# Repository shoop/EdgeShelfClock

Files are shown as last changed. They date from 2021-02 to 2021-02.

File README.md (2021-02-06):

# Edge Shelf Clock
This is my version of [the Edge Shelf Clock](https://www.diymachines.co.uk/how-to-build-a-giant-hidden-shelf-edge-clock). Notably it uses 4 full digits to accomodate 24 hour clock.

Documentation in the `docs` folder:
- construction.drawio - drawing of the parameters when constructing
- schematic.fzz - Fritzing file for the breadboard setup

Also some datasheets for the used components.

BOM:
- 1 x ESP8266
- 1 x DS3231 RTC module
- 1 x PhotoResistor module for Arduino
- 1 x barrel jack connector
- 2 x 470 ohm resistor
- 1 x 1000uF capacitor
- 1 x 5V 10A power supply with barrel jack
- 1 x AdaFruit perma proto board
- red/green/black wire
- printed components (see `3dprinter` folder and [thingiverse](https://www.thingiverse.com/thing:4207524))
- wooden backboard
- screws

Tools in the `tools/` subfolder are not very configurable but work on my Linux machine. Adjust to taste.

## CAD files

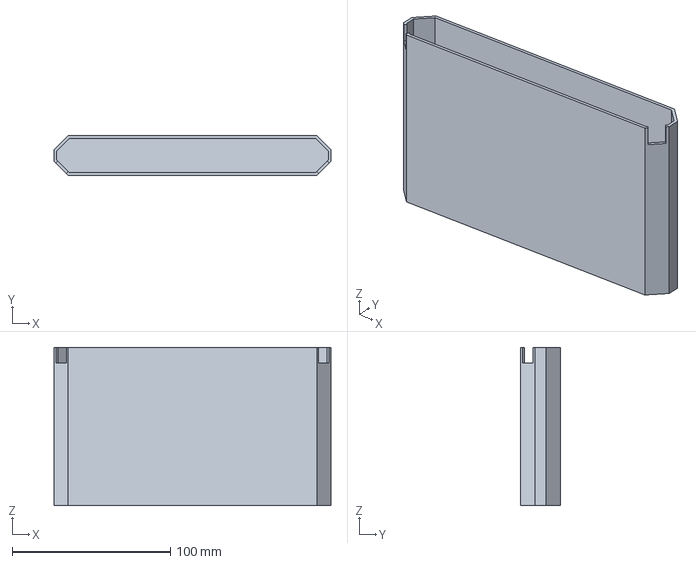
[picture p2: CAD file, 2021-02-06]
3dprinter/DualColored - Sleeve 1.3mf
175.0 x 25.0 x 100.0 mm

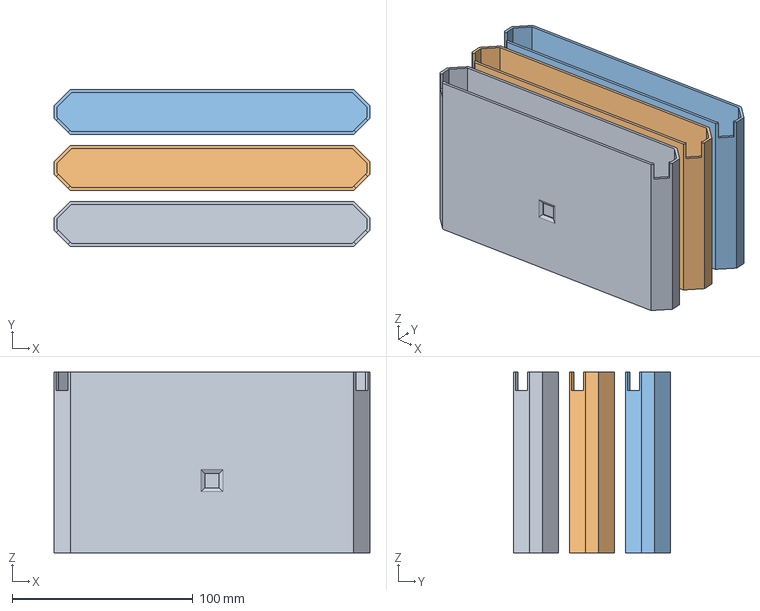
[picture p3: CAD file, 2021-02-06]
3dprinter/DualColored - Sleeve 2.3mf
175.0 x 87.0 x 100.0 mm
Sleeve2.STL x 3

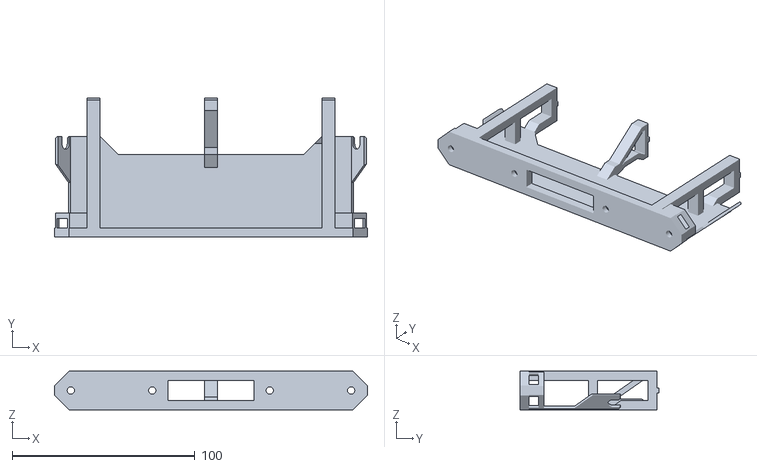
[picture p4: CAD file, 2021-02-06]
3dprinter/STL/Core4-Arduino.STL
171.1 x 76.0 x 21.1

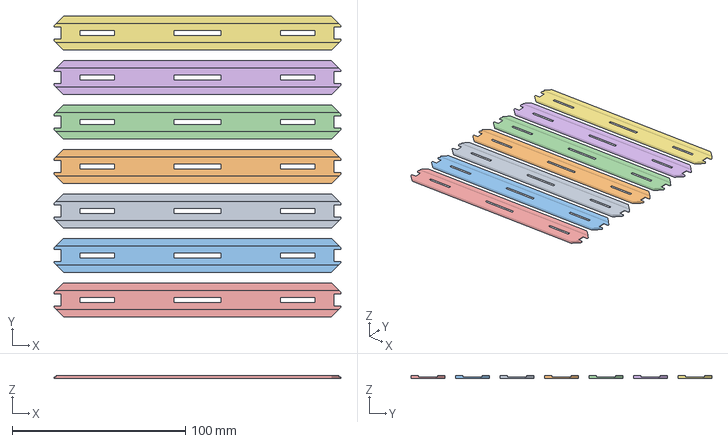
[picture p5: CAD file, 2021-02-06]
3dprinter/LEDMounts.3mf
165.7 x 173.9 x 2.00 mm
LEDMount.STL x 7

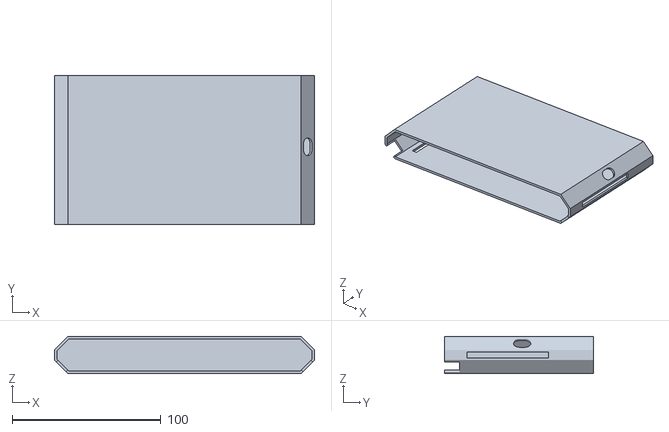
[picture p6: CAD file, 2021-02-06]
3dprinter/STL/Sleeve5.STL
175.0 x 100.0 x 25.0

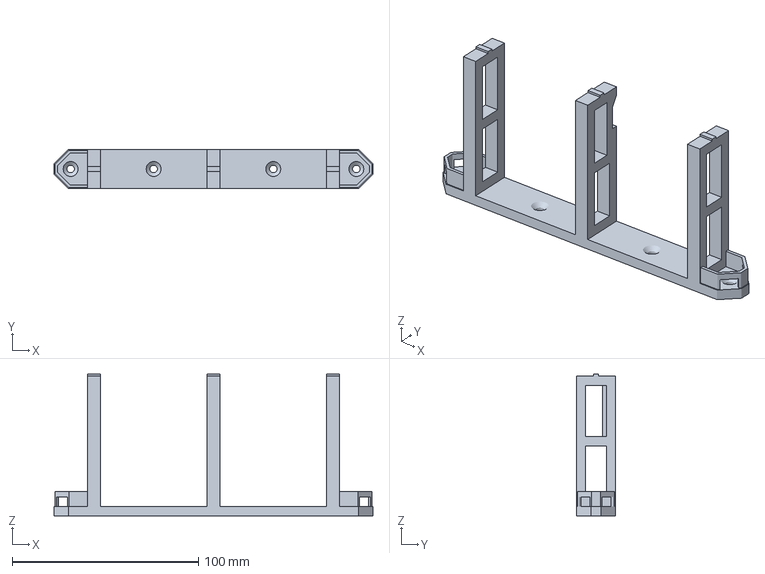
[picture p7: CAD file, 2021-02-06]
3dprinter/Core 2.3mf
171.1 x 21.1 x 76.0 mm

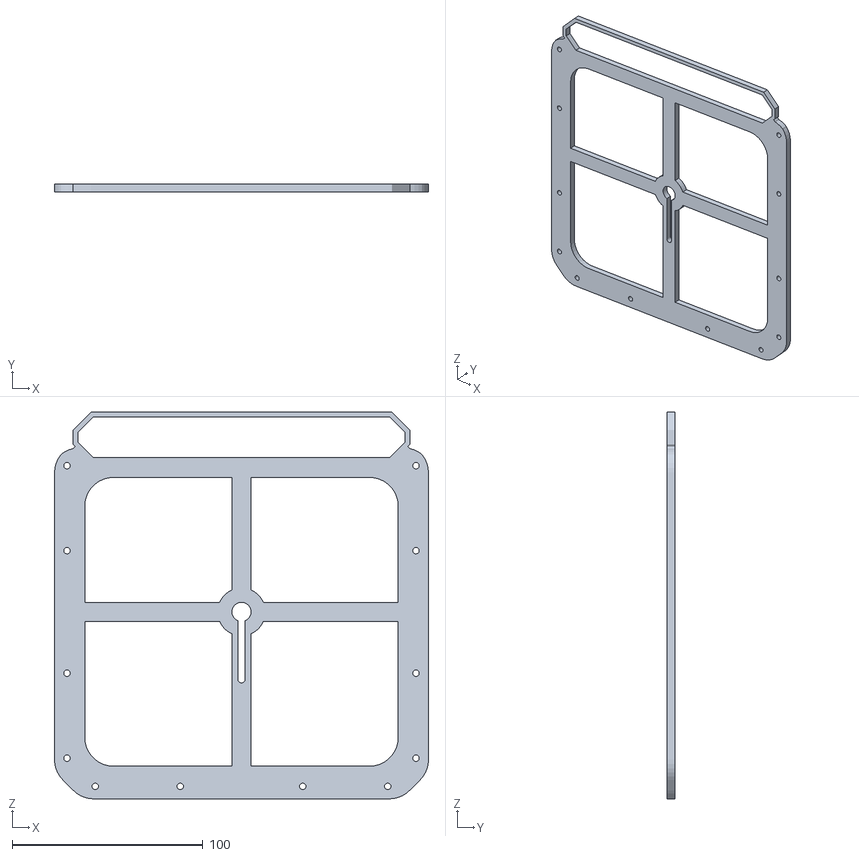
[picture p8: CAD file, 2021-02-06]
3dprinter/STL/Template2.STL
195.9 x 4.00 x 202.6

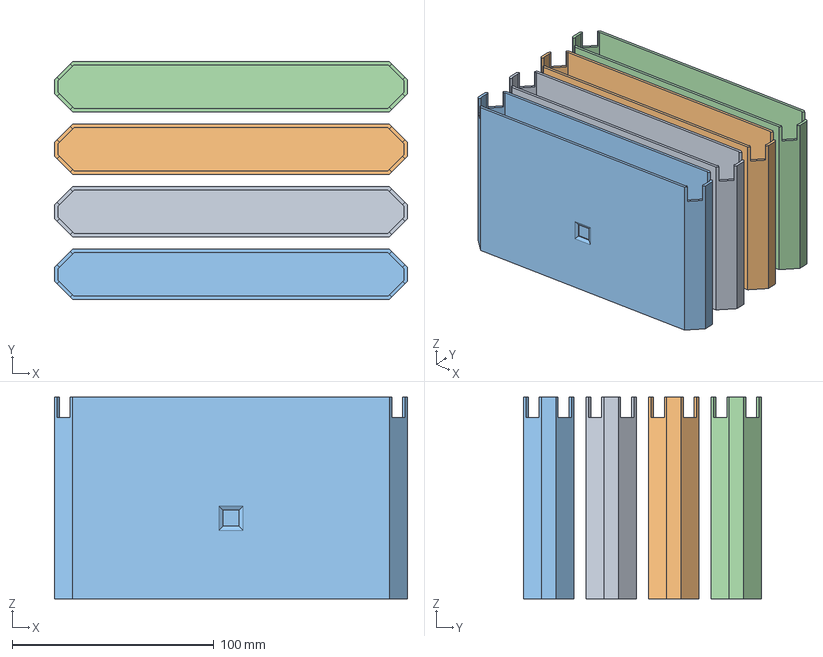
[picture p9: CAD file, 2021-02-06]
3dprinter/DualColored - Sleeve 4.3mf
175.0 x 118.0 x 100.0 mm
Sleeve4.STL x 4

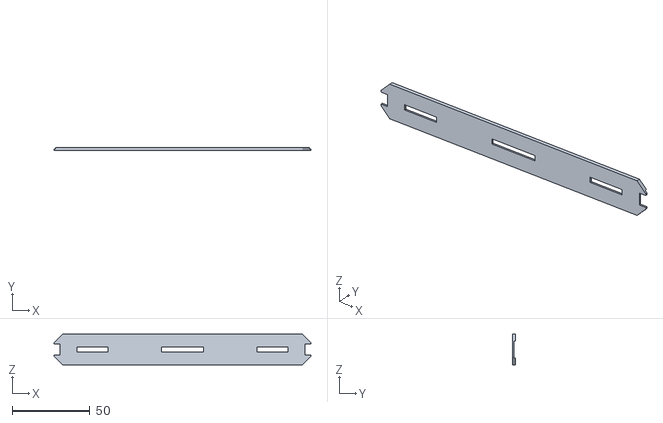
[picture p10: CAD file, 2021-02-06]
3dprinter/STL/LEDMount.STL
165.7 x 2.00 x 19.7

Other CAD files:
3dprinter/STL/Sleeve1.STL
3dprinter/DualColored - Sleeve 3.3mf
3dprinter/STL/Sleeve4.STL
3dprinter/STL/Sleeve3.STL
3dprinter/DualColored - Sleeve 5.3mf
3dprinter/STL/Sleeve2.STL
3dprinter/STL/Core2.STL

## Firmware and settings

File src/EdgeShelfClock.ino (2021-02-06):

#define OTA_VERSION 1

// WiFi connection
#include <ESP8266WiFi.h>
#include <ESP8266WebServer.h>

/*
 * Enter your SSID & Password here to connect for the first time.
 * Once the sketch has been run at least once, the values will be stored
 * on the ESP8266 by the WiFi system. You can then safely remove them
 * from here again and leave the empty string -- this will reconnect
 * to your previous AP.
 */
const char *ssid = "";
const char *password = "";

// Filesystem
#include <LittleFS.h>

// LED configuration
#define FASTLED_ESP8266_RAW_PIN_ORDER
#include <FastLED.h>
#define CLOCK_PIN 14 // GPIO14 aka D5
#define SHELF_PIN 12 // GPIO12 aka D6

#define NR_LINE_LEDS 9
#define NR_DIGIT_LEDS (NR_LINE_LEDS * 7)
#define NR_DIGITS 4
#define NR_CLOCK_LEDS (NR_DIGITS * NR_DIGIT_LEDS)
#define NR_SHELF_LEDS 14

#define MAX_BRIGHTNESS 128

CRGB clockleds[NR_CLOCK_LEDS];
CRGB clockcolor = CRGB::White;
int clockBrightness = MAX_BRIGHTNESS / 2;
CRGB shelfleds[NR_SHELF_LEDS];
CRGB shelfcolor = CRGB::White;
int shelfBrightness = MAX_BRIGHTNESS / 2;

enum StripState {
  Off = 0,
  On = 1,
};

// Numbered backwards for easy offsets
enum ClockDigit {
  M2 = 0,
  M1 = 1,
  H2 = 2,
  H1 = 3,
};

enum StripState clockstatus = On;
enum StripState shelfstatus = Off;

#define FRAMES_PER_SECOND  60

// Uncomment for the real clock, otherwise 8 test leds are used
#define REAL_CLOCK_STRIP 1

// Webserver configuration
ESP8266WebServer server(80);
String prehtml;
String posthtml;

// Real time clock and NTP
#include <Wire.h>
#define I2S_SDA_PIN 4 // GPIO4 aka D2
#define I2S_SCL_PIN 5 // GPIO5 aka D1

#include <AceRoutine.h>
#include <AceTime.h>
using namespace ace_routine;
using namespace ace_time;
using namespace ace_time::clock;

DS3231Clock dsClock;
NtpClock ntpClock("europe.pool.ntp.org");
SystemClockCoroutine systemClock(&ntpClock, &dsClock);
static BasicZoneProcessor zoneProcessor;

#define VERBOSE 0

// Photoresistor
#define NUM_READINGS  12
int readings[NUM_READINGS];
int readIndex = 0;
long total = 0;
long average = 0;

// OTA
#include <ArduinoOTA.h>
#define OTA_HOSTNAME "edgeshelfclock"
// admin123
// Change to something for your environment
#define OTA_PASSWORD_HASH "0192023a7bbd73250516f069df18b500"

String otaVersion = String(OTA_VERSION);

void setup()
{
  Serial.begin(115200);
  delay(1000);
  Serial.println();

  // Set up leds
  Serial.printf("Setting up clock pixel strip on pin %d\n", CLOCK_PIN);
  FastLED.addLeds<NEOPIXEL, CLOCK_PIN>(clockleds, NR_CLOCK_LEDS);
  Serial.printf("Setting up shelf pixel strip on pin %d\n", SHELF_PIN);
  FastLED.addLeds<NEOPIXEL, SHELF_PIN>(shelfleds, NR_SHELF_LEDS);

  // Initialize brightness settings
  FastLED.setBrightness(MAX_BRIGHTNESS);
  for (int i = 0; i < NUM_READINGS; i++) {
    readings[i] = 0;
  }

  // Set up filesystem
  LittleFS.begin();

  // Set up WiFi
  if (ssid != "") {
    Serial.printf("Connecting to SSID \"%s\"", ssid);
  } else {
    Serial.print(F("Connecting to previously defined AP"));
  }
  WiFi.begin(ssid, password);
  while (WiFi.status() != WL_CONNECTED) {
    delay(1000);
    Serial.print(".");
  }
  Serial.println("");
  Serial.printf("Connected, IP %s\n", WiFi.localIP().toString().c_str());

  // Set up RTC and NTP
  Serial.printf("Setting up I2S bus SDA pin %d SCL pin %d\n", I2S_SDA_PIN, I2S_SCL_PIN);
  Wire.begin(I2S_SDA_PIN, I2S_SCL_PIN);
  Serial.println(F("Setting up DS3231 RTC"));
  dsClock.setup();
  Serial.println(F("Setting up NTP"));
  ntpClock.setup();
  Serial.println(F("Setting up SystemClock coroutine"));
  systemClock.setupCoroutine(F("systemClock"));
  CoroutineScheduler::setup();

  // Print current RTC time for debugging
  Serial.print(F("RTC current date/time at startup: "));
  auto tz = TimeZone::forZoneInfo(&zonedb::kZoneEurope_Amsterdam, &zoneProcessor);
  acetime_t rtcNow = dsClock.getNow();
  auto rtcDateTime = ZonedDateTime::forEpochSeconds(rtcNow, tz);
  rtcDateTime.printTo(Serial);
  Serial.println();

  // Set up webserver
  File templ = LittleFS.open("/template.html", "r");
  if (!templ) {
    Serial.println(F("ERROR: HTML template /template.html not found, looping!"));
    while (1) ;
  }
  prehtml = templ.readStringUntil('@');
  posthtml = templ.readString();
  templ.close();

  Serial.println(F("Starting webserver..."));
  server.on("/", handleConnect);
  server.on("/set", HTTP_POST, handleSet);
  server.onNotFound(handleNotFound);
  server.begin();

  // Set up OTA
  ArduinoOTA.setPort(8266); // Default
  ArduinoOTA.setHostname(OTA_HOSTNAME);
  ArduinoOTA.setPasswordHash(OTA_PASSWORD_HASH);

  ArduinoOTA.onStart([]() {
    String type;
    if (ArduinoOTA.getCommand() == U_FLASH) {
      type = "sketch";
    } else { // U_FS
      type = "filesystem";
    }

    // NOTE: if updating FS this would be the place to unmount FS using FS.end()
    LittleFS.end();
    Serial.println("Start updating " + type);
  });
  ArduinoOTA.onEnd([]() {
    Serial.println("\nEnd");
  });
  ArduinoOTA.onProgress([](unsigned int progress, unsigned int total) {
    Serial.printf("Progress: %u%%\r", (progress / (total / 100)));
  });
  ArduinoOTA.onError([](ota_error_t error) {
    Serial.printf("Error[%u]: ", error);
    if (error == OTA_AUTH_ERROR) {
      Serial.println("Auth Failed");
    } else if (error == OTA_BEGIN_ERROR) {
      Serial.println("Begin Failed");
    } else if (error == OTA_CONNECT_ERROR) {
      Serial.println("Connect Failed");
    } else if (error == OTA_RECEIVE_ERROR) {
      Serial.println("Receive Failed");
    } else if (error == OTA_END_ERROR) {
      Serial.println("End Failed");
    }
  });
  ArduinoOTA.begin();

  // Ready
  Serial.printf("Accepting connections at http://%s\n", WiFi.localIP().toString().c_str());
}

void clearClock()
{
  fill_solid(clockleds, NR_CLOCK_LEDS, CRGB::Black);
}

void setClockDigitTest(int value, ClockDigit digit, CRGB color)
{
  // Use the first 8 leds I have on the test strip to "display the time"
  int offset = digit * 2;
  CRGB mapping[5] = { CRGB::Red, CRGB::Blue, CRGB::Yellow, CRGB::Green, CRGB::White };

  switch (value % 10) {
    case 0:
    case 1:
    case 2:
    case 3:
    case 4:
      fill_solid(&clockleds[offset], 1, mapping[value % 5]);
      break;
    case 5:
    case 6:
    case 7:
    case 8:
    case 9:
      fill_solid(&clockleds[offset], 1, mapping[value % 5]);
      fill_solid(&clockleds[offset + 1], 1, color);
      break;
  }
}

void setClockDigitReal(int value, ClockDigit digit, CRGB color)
{
  int offset = digit * NR_DIGIT_LEDS;
  switch (value % 10) {
    case 0:
      fill_solid(&clockleds[offset], 27, color);
      fill_solid(&clockleds[offset + 36], 27, color);
      break;
    case 1:
      fill_solid(&clockleds[offset], 9, color);
      fill_solid(&clockleds[offset + 36], 9, color);
      break;
    case 2:
      fill_solid(&clockleds[offset], 18, color);
      fill_solid(&clockleds[offset + 27], 9, color);
      fill_solid(&clockleds[offset + 45], 18, color);
      break;
    case 3:
      fill_solid(&clockleds[offset], 18, color);
      fill_solid(&clockleds[offset + 27], 27, color);
      break;
    case 4:
      fill_solid(&clockleds[offset], 9, color);
      fill_solid(&clockleds[offset + 18], 27, color);
      break;
    case 5:
      fill_solid(&clockleds[offset + 9], 45, color);
      break;
    case 6:
      fill_solid(&clockleds[offset + 9], 54, color);
      break;
    case 7:
      fill_solid(&clockleds[offset], 18, color);
      fill_solid(&clockleds[offset + 36], 9, color);
      break;
    case 8:
      fill_solid(&clockleds[offset], 63, color);
      break;
    case 9:
      fill_solid(&clockleds[offset], 45, color);
      break;
  }
}

void clearShelf()
{
  fill_solid(shelfleds, NR_SHELF_LEDS, CRGB::Black);
}

void turnShelfOn()
{
  fill_solid(shelfleds, NR_SHELF_LEDS, shelfcolor);
}

void loop()
{
  ArduinoOTA.handle();

  EVERY_N_MILLISECONDS(1000) {
    // Read brightness
    int curBrightness = analogRead(0);
    readings[readIndex] = curBrightness;
    readIndex++;
    if (readIndex >= NUM_READINGS) {
      readIndex = 0;
    }

    // Calculate average so far 
    int sumBrightness = 0;
    for (int i = 0; i < NUM_READINGS; i++) {
      sumBrightness += readings[i];
    }
    int avgBrightness = sumBrightness / NUM_READINGS;
    clockBrightness = map(avgBrightness, 50, 1000, MAX_BRIGHTNESS, 10);
  }

  EVERY_N_MILLISECONDS(200) {
    // Set clock and shelf leds
    FastLED.setBrightness(clockBrightness);
    clearClock();
    if (clockstatus == On) {
      acetime_t now = systemClock.getNow();
      auto tz = TimeZone::forZoneInfo(&zonedb::kZoneEurope_Amsterdam, &zoneProcessor);
      auto currentDateTime = ZonedDateTime::forEpochSeconds(now, tz);
      uint8_t minute = currentDateTime.minute();
      uint8_t hour = currentDateTime.hour();
#if defined(REAL_CLOCK_STRIP)
      setClockDigitReal(minute % 10, M2, clockcolor);
      setClockDigitReal(minute / 10, M1, clockcolor);
      setClockDigitReal(hour % 10, H2, clockcolor);
      setClockDigitReal(hour / 10, H1, clockcolor);
#else
      uint8_t seconds = currentDateTime.second();
      setClockDigitTest(seconds % 10, M2, clockcolor);
      setClockDigitTest(seconds / 10, M1, clockcolor);
      setClockDigitTest(minute % 10, H2, clockcolor);
      setClockDigitTest(minute / 10, H1, clockcolor);
#endif
    }

    FastLED.setBrightness(shelfBrightness);
    if (shelfstatus == On) {
      turnShelfOn();
    } else if (shelfstatus == Off) {
      clearShelf();
    }
  }

  EVERY_N_MILLISECONDS(30000) {
    acetime_t now = systemClock.getNow();
#if VERBOSE
    Serial.print("Current date/time: ");
#endif
    auto tz = TimeZone::forZoneInfo(&zonedb::kZoneEurope_Amsterdam, &zoneProcessor);
    auto currentDateTime = ZonedDateTime::forEpochSeconds(now, tz);
#if VERBOSE
    currentDateTime.printTo(Serial);
    Serial.println();
#endif
  }

  FastLED.show();
  
  server.handleClient();

  CoroutineScheduler::loop();

  FastLED.delay(1000 / FRAMES_PER_SECOND);
}

void handleConnect()
{
  server.send(200, "text/html", generateHtml()); 
}

void redirectToMain()
{
  server.sendHeader("Location", String("/"), true);
  server.send(302, "text/plain", "");
}

void handleSet()
{
  if (!server.hasArg("lights")) {
    Serial.println(F("No lights parameter send by browser"));
    redirectToMain();
    return;
  }
  String lights = server.arg("lights");
  if (lights != "clock" && lights != "shelf") {
    Serial.println(F("Invalid lights parameter send by browser"));
    redirectToMain();
    return;
  }

  if (!server.hasArg("selection")) {
    Serial.println(F("No selection parameter send by browser"));
    redirectToMain();
    return;
  }
  String selection = server.arg("selection");
  if (selection != "on" && selection != "off" && selection != "color") {
    Serial.println(F("Invalid selection parameter send by browser"));
  }

  CRGB temp = CRGB::White;
  if (selection == "color") {
    if (!server.hasArg("color")) {
      Serial.println(F("No color parameter send by browser"));
      redirectToMain();
      return;
    }
    String color = server.arg("color");
    if (sscanf(color.c_str(), "rgb(%hhu,%hhu,%hhu)", &temp.r, &temp.g, &temp.b) != 3) {
      Serial.println("Color parameter not in correct format, got " + color);
      redirectToMain();
      return;
    }
  }

  Serial.printf("%s: %s\n", lights.c_str(), selection.c_str());
  if (lights == "clock" ) {
    if (selection == "on") {
      clockstatus = On;
    } else if (selection == "off") {
      clockstatus = Off;
    } else if (selection == "color") {
      clockcolor = temp;
    }
  } else if (lights == "shelf") {
    if (selection == "on") {
      shelfstatus = On;
    } else if (selection == "off") {
      shelfstatus = Off;
    } else if (selection == "color") {
      shelfcolor = temp;
    }
  }

  redirectToMain();
}

String getContentType(String filename) {
  if (filename.endsWith(".html")) return "text/html";
  else if (filename.endsWith(".css")) return "text/css";
  else if (filename.endsWith(".js")) return "application/javascript";
  else if (filename.endsWith(".ico")) return "image/x-icon";
  return "text/plain";
}

bool handleFileRead(String path)
{
  if (path.endsWith("/")) path += "index.html";
  String contentType = getContentType(path);
  if (!LittleFS.exists(path)) {
    return false;
  }

  File file = LittleFS.open(path, "r");
  size_t sent = server.streamFile(file, contentType);
  file.close();
  return true;
}

void handleNotFound()
{
  if (!handleFileRead(server.uri()))
    server.send(404, "text/plain", "404: Not Found");  
}

void append_post_button(String *html, String strip, String selection, String text)
{
  *html += "<form method=\"post\" action=\"/set\"><input type=\"hidden\" name=\"lights\" value=\"" + strip + "\">"
        + "<button type=\"submit\" name=\"selection\" value=\"" + selection + "\" class=\"button button-" + selection + "\">"
        + text
        + "</button>"
        + "</form>\n";
}

void append_color_picker(String *html, String strip, String text, CRGB current)
{
  char valbuf[18];
  sprintf(valbuf, "rgb(%d,%d,%d)", current.r, current.g, current.b);
  valbuf[17] = '\0';
  *html += "<form method=\"post\" action=\"/set\"><input type=\"hidden\" name=\"lights\" value=\"" + strip + "\">"
        + "Select " + strip + " color:<br/><input name=\"color\" data-jscolor=\"{format:'rgb'}\" value=\"" + valbuf + "\")>"
        + "<button type=\"submit\" name=\"selection\" value=\"color\" class=\"button\">" + text + "</button>"
        + "</form>\n";
}

String generateHtml()
{
  String ptr = "";
  ptr += prehtml;
  
  if (clockstatus == On) {
    ptr +="<p>Clock Status: ON</p>";
    append_post_button(&ptr, "clock", "off", "OFF");
  } else if (clockstatus == Off) {
    ptr +="<p>Clock Status: OFF</p>";
    append_post_button(&ptr, "clock", "on", "ON");
  }

  ptr += "<p>";
  append_color_picker(&ptr, "clock", "SET", clockcolor);
  ptr += "</p>";

  if (shelfstatus == On) {
    ptr +="<p>Shelf Status: ON</p>";
    append_post_button(&ptr, "shelf", "off", "OFF");
  } else if (shelfstatus == Off) {
    ptr +="<p>Shelf Status: OFF</p>";
    append_post_button(&ptr, "shelf", "on", "ON");
  }

  ptr += "<p>";
  append_color_picker(&ptr, "shelf", "SET", shelfcolor);
  ptr += "</p>";

  // TEMP
  ptr += "<p>Version " + otaVersion + "</p>";

  ptr += posthtml;
  return ptr;
}

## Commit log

2021-01-01 Ensure VS Code picks up correct Wire.h header
2021-01-03 Add photoresistor on pin A0
2021-02-06 Fix FastLED include squigglies
    [EdgeShelfClock.ino]
2021-02-06 Reset to version 1 now that it is tested
    [EdgeShelfClock.ino]
2021-02-06 Add documentation and 3D printer files
    [Core 2.3mf, Core2.STL, Core4-Arduino.STL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]
